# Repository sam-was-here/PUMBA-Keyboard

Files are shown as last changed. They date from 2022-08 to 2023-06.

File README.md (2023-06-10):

# PUMBA-Keyboard

PUMBA-Keyboard is a PS2 to USB macro board adapter created using the Arduino framework.

PUMBA stands for PS2 to USB Macro Board Adapter.

## Description

PUMBA-Keyboard is an Arduino project that converts a PS2 keyboard into a USB keyboard with additional features. It includes a built-in calculator and the ability to create and playback macros. The board also has a small display for showing different information.

PUMBA-Keyboard

### Features
Here is a list of features offered by PUMBA-Keyboard:
* Six different keyboard modes, allowing each key to have a different assigned macro.
* Easy on-the-fly macro creation without the need for PC software.
* All settings and macros are stored on the SD card, making modification and backup effortless.
* Calculator mode that turns a part or the whole keyboard into a calculator, sending results as keypresses.
* Numpad can be converted into a calculator in any of the six keyboard modes while leaving the rest of the keyboard untouched.
* Hex and decimal converter mode.
* Numlock is automatically enabled during startup and mode changes.
* Ability to rebind keys and have different key layouts for each keyboard mode (partially implemented).
* Key bindings can be changed without requiring the SD card to be inserted into a PC.

## Compatibility

PUMBA has been tested with SAMD21 and SAMD51 microcontroller boards. The project may work with most microcontrollers capable of emulating a HID device. However, it is not compatible with Arduino Leonardo or Uno boards due to limited available RAM. Most PS2 keyboards have been tested successfully, but it may not work with USB keyboards using a USB to PS2 adapter. The code was written using PlatformIO with the Arduino framework.

Tested Boards:
* Adafruit Feather M4 Express
* Adafruit QT Py SAMD21
* Seeeduino Xiao

## PCB and Cases

PCB and case designs are available for this project. However, they are not mandatory, as you can integrate everything inside a keyboard or use a breadboard. The repository includes KiCad project files, PDFs of the schematic, PCBs, and a bill of materials (BOM).

## Keyboard Modes

The PUMBA keyboard offers six different keyboard modes, each with its own layouts and macros. One mode is dedicated to functioning solely as a calculator, but all keyboard modes can activate the numpad as a calculator. Another mode is a hex and decimal converter, while one keyboard mode does not support macros.

When the PUMBA keyboard is plugged into a computer, it automatically enters "Keyboard 1" mode. You can switch between modes by pressing the "function key," which is set as the default to the menu button. After pressing the function key, the display shows available actions. To switch modes, press the corresponding key for the desired mode. Pressing the function key again takes you to the second-to-last mode.

### Key Assignments
Here is a list of key assignments for mode switching:
* 1: Keyboard 1
* 2: Keyboard 2
* 3: Keyboard 3
* 4: Keyboard 4
* 5: Keyboard 5
* 6: Keyboard 6
* 7: Not assigned
* 8: Hex and decimal converter
* 9: Calculator

* 0: Keyboard mode with no macros
* Shift + 1-6: Keyboard mode with calculator functionality on the numpad
* Ctrl + 1-6: Program macros/rebind keys for a key in the mode. The display provides instructions.

## Calculator Controls

The calculator mode on the PUMBA keyboard includes the following controls:
* Num Lock / Backspace: Delete the last character.
* Scroll Lock: Type out the answer using key strokes.
* Delete: Clear the current number, last number, and operator.
* =/Enter: Calculate and display the answer.
* /-+*. : Perform corresponding operations.
* x: Multiply.
* t p: Add.
* Page Up/Down: Change the number of decimal points shown.

## Macros and Key Rebinding

When creating macros, they are stored on the micro SD card inserted into the device. If no SD card is present, all keyboard modes will act as normal keyboards. If there are no settings on the SD card or it is not inserted, the device will revert to default settings.

The following Arduino libraries are used by this program:
1. PS2KeyAdvanced (located in the "lib" folder)
2. HID-Project
3. Adafruit_GFX and Adafruit_sm1306 (for OLED display support)
4. SD

To learn how to use the PS2KeyAdvanced library, refer to the documentation at [https://github.com/techpaul/PS2KeyAdvanced](https://github.com/techpaul/PS2KeyAdvanced).

This project utilizes Project-hid for USB keyboard functionality. Refer to the documentation at [https://github.com/NicoHood/HID](https://github.com/NicoHood/HID).

The PS2KeyAdvanced library in the "lib" folder has been modified to disable keypad switching keybindings and modify lock keys to prevent issues.

* Num Lock is now PS2_KEY_LANG1.
* Scroll Lock is now PS2_KEY_LANG2.
* Caps Lock is now PS2_KEY_LANG3.
* Sending data (Lock LED) to the PS2 keyboard does not work with SAMD boards.

## Changing Settings

On the PUMBA Keyboard, you can change settings such as the screen timeout duration, screen rotation, and the function key. Currently, there is no way to change these settings using the keyboard directly, but you can modify them in the code or by creating a settings file on the SD card. On startup, PUMBA looks for a config file named "CONFIG.TXT" located in the "/SETTING" folder on the SD card to apply the settings.

To change settings using the SD card, follow these steps:
1. Create a file named "CONFIG.TXT" in a folder named "SETTING" on the SD card.
2. In the config file, enter the name of the setting followed by an "=" sign. Each setting should be on a new line.
   * sleep=SETTING
     * SETTING: The duration in minutes before the screen turns off.
   * fnkey=SETTING
     * SETTING: The PS2lib key binding in decimal for the function key.
   * rotation=SETTING
     * SETTING: The screen rotation value. 0 is default, 2 is rotated 180 degrees.
3. Save the changes to the file.
4. Insert the SD card into PUMBA and plug it in.

## Key Rebinding

PUMBA now supports the ability to rebind keys for each keyboard mode. To rebind keys, create a file named "LAYOUT.TXT" and place it in the mode for which you want to rebind the keys. Each line in the file corresponds to a PS2lib key name and the corresponding HID scancode in

 decimal. In the code files, you can find a file called "default layout.txt" which contains the default key bindings. You can make a copy of this file, rename it, and modify it according to your needs. Additionally, there is a file named "layout cheatsheet.txt" that provides a helpful reference.

In any of the 6 modes, you can set macros or rebind almost any key on the keyboard. However, please note that some keys such as Scroll Lock, Num Lock, and Pause Break may not be compatible with macros or key rebindings.

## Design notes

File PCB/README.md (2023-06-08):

Located here is the KiCad project for the PCB used in the PUMBA-Keyboard. Additionally, the Gerber files are also available here.

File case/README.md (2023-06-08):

Located here is the FreeCAD model and STLs for the case of the PUMBA-Keyboard. There are two parts to the case: the main case and the face. You can 3D print them for yourself. If I recall correctly, there is a mistake in the case model that interferes with the components and the PCB. To work around this problem, you can use a Dremel tool to fix the 3D model or modify it in FreeCAD.

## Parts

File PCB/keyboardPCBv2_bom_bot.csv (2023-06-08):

Comment | Designator | Footprint | LCSC Part #
Conn_01x05_Female | J1
SolderJumper_3_Bridged12 | JP1 JP2
PS2_Port | P1
SeeeduinoXIAO | QT_Board1
Conn_01x04_Female | Screen1

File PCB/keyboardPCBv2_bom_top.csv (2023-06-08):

Comment | Designator | Footprint | LCSC Part #
BSS138 | Q1 Q2 | SOT-23-3 | C400505
R 10k | R1 R2 R3 R4 | 0603 | C25804
cheap_microSD | U1 | TF-SMD_TF-15-15 | C111196

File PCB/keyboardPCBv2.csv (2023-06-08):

Source: | /home/sam/Documents/kicad/keyboardPCBv2/keyboardPCBv2/keyboardPCBv2.kicad_sch
Date: | Sat 23 Apr 2022 04:06:03 PM CDT
Tool: | Eeschema 6.0.2
Generator: | /app/share/kicad/plugins/bom_csv_grouped_by_value_with_fp.py
Component Count: | 14
Ref | Qnty | Value | Cmp name | Footprint | Description | Vendor
Feather_Board1, | 1 | Adafruit_Feather_M0_Express | Adafruit_Feather_M0_Express | Module:Adafruit_Feather | Microcontroller module with SAMD21 Cortex-M0 MCU and SPI Flash
J2, | 1 | Conn_01x05_Female | Conn_01x05_Female | Connector_PinSocket_2.54mm:PinSocket_1x05_P2.54mm_Vertical | Generic connector, single row, 01x05, script generated (kicad-library-utils/schlib/autogen/connector/)
JP1, JP2, | 2 | SolderJumper_3_Bridged12 | SolderJumper_3_Bridged12 | Jumper:SolderJumper-3_P1.3mm_Bridged12_RoundedPad1.0x1.5mm | 3-pole Solder Jumper, pins 1+2 closed/bridged
P1, | 1 | PS2_Port | Mini-DIN_6pins_ver4 | Custom_Footprints:Connector_Mini-DIN_Female_6Pin_2rows
Q1, Q2, | 2 | BSS138 | BSS138 | Package_TO_SOT_SMD:SOT-23 | 50V Vds, 0.22A Id, N-Channel MOSFET, SOT-23
QT_Board1, | 1 | SeeeduinoXIAO | SeeeduinoXIAO | Seeeduino XIAO KICAD:Seeeduino XIAO-MOUDLE14P-2.54-21X17.8MM
R1, R2, R3, R4, | 4 | R 10k | R | Resistor_SMD:R_0603_1608Metric_Pad0.98x0.95mm_HandSolder | Resistor
Screen1, | 1 | Conn_01x04_Female | Conn_01x04_Female | Connector_PinSocket_2.54mm:PinSocket_1x04_P2.54mm_Vertical | Generic connector, single row, 01x04, script generated (kicad-library-utils/schlib/autogen/connector/)
SPI_MICROSD1, | 1 | Micro_SD_Card | Micro_SD_Card | Connector_Card:microSD_HC_Hirose_DM3D-SF | Micro SD Card Socket

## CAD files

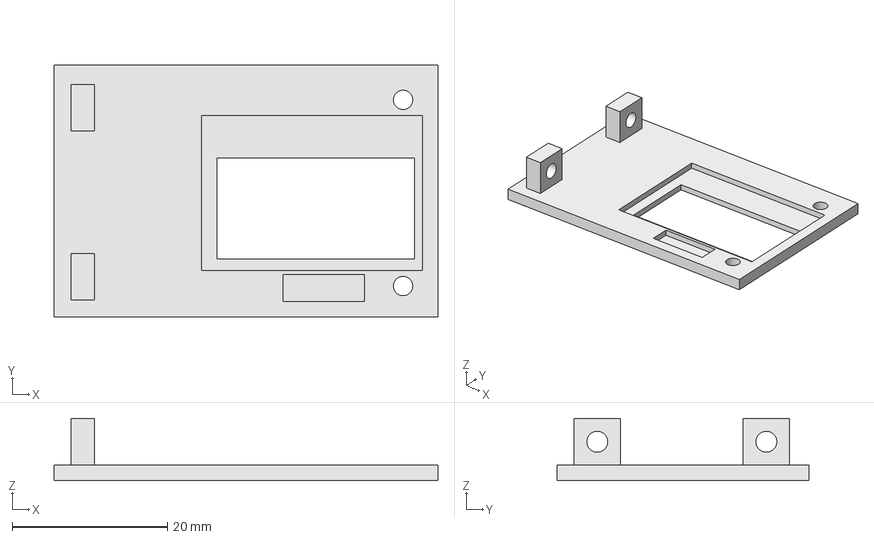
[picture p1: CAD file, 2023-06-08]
case/keyboardPCD v2 face.FCStd
49.5 x 32.5 x 8.00 mm

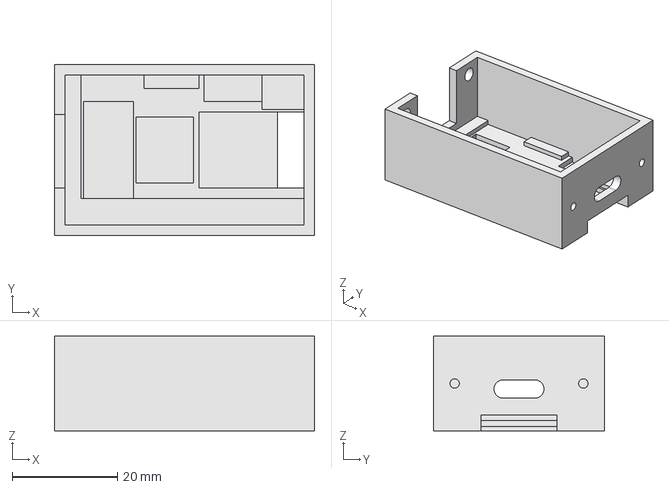
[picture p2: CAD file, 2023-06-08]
case/keyboardPCD v2 case.FCStd
49.5 x 32.5 x 18.0 mm

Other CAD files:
case/keyboardPCD v2 face-Body.stl
case/keyboardPCD v3 case-Body.stl
case/keyboardPCD v2 case-Body.stl

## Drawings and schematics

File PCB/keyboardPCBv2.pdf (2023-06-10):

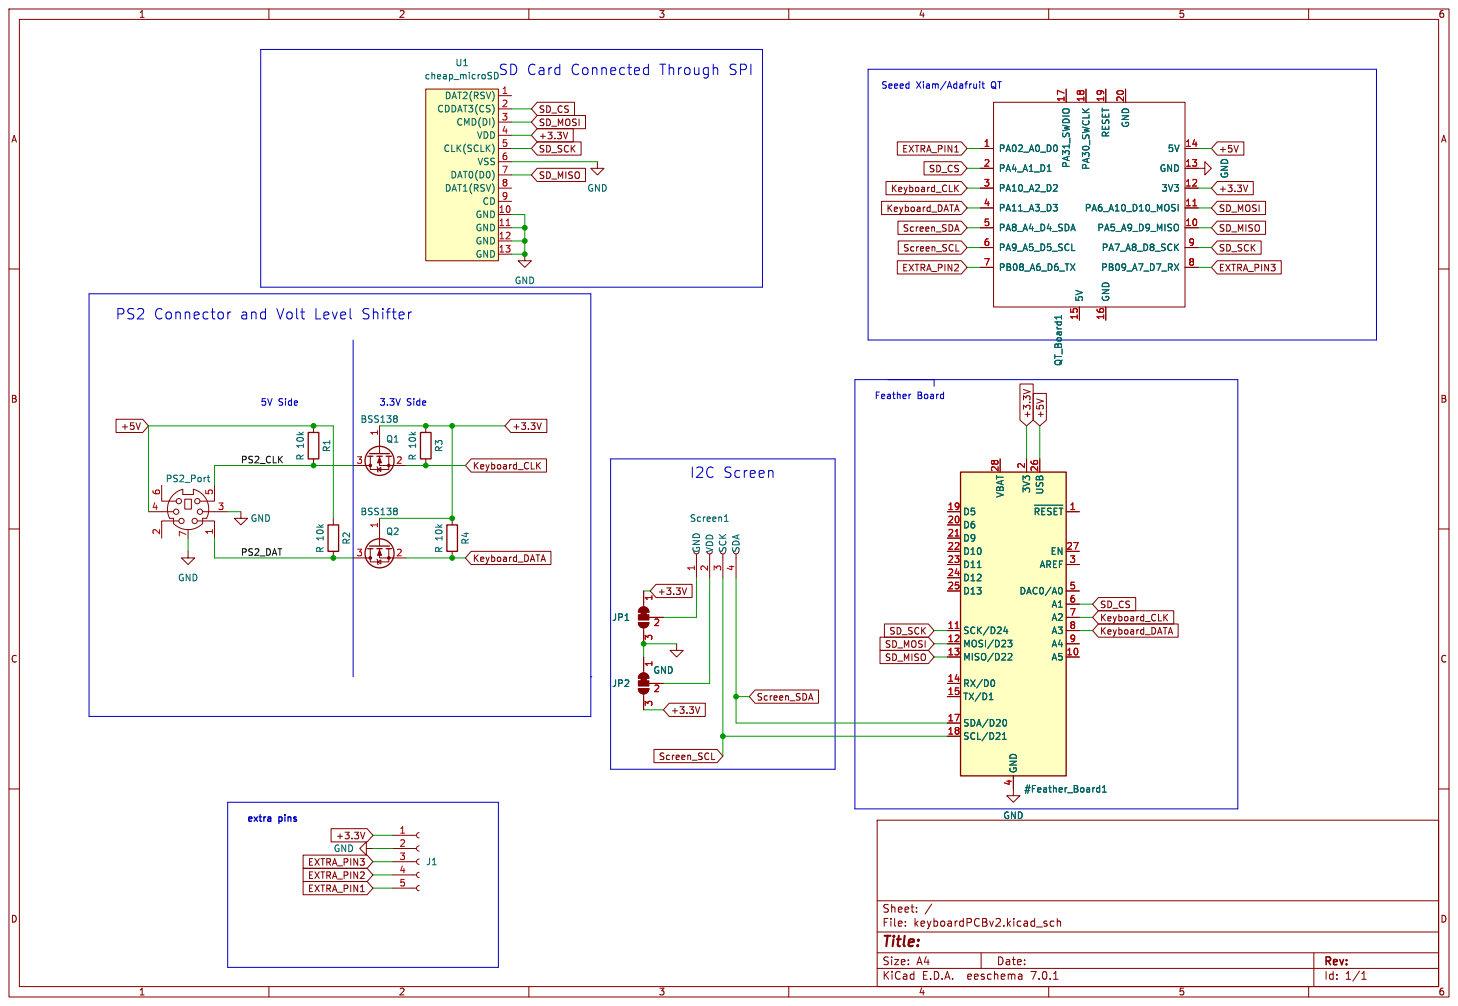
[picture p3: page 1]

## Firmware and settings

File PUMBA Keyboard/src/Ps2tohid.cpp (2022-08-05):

// <this program converts a PS2 keyboard to a USB keyboard and add extra functionality>
// Copyright (C) <2022>  <Sam Kim>

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
#include "Arduino.h"
#include "Ps2tohid.h"
#include <PS2KeyAdvanced.h>
PS2KeyAdvanced keyboard1;
#include <HID-Project.h>
#include <HID-Settings.h>
#include <SPI.h>
#include <SD.h>

#include <Wire.h>
#include <Adafruit_GFX.h>
#include <Adafruit_SSD1306.h>

// need to get from this info from begin funtion
#define SCREEN_WIDTH 128 // OLED display width, in pixels
#define SCREEN_HEIGHT 64 // OLED display height, in pixels
#define OLED_RESET -1    // Reset pin # (or -1 if sharing Arduino reset pin)
//#define SCREEN_ADDRESS 0x3C ///< See datasheet for Address; 0x3D for 128x64, 0x3C for 128x32

Adafruit_SSD1306 display1(SCREEN_WIDTH, SCREEN_HEIGHT, &Wire, OLED_RESET);

// initalized functions befor they are used
void _macroFinder();
int keyboardCheck();
bool sdStatus();
byte displayRotation();
void setLayout();

// int _solveHexDec(String currentHexDec);

/*!
    @brief  This constuter is used to set the defualt settings for the keyboard and gets things setted up. note all the setting can be change with the SD card.
    @param  interval
            The time in minuise that it takes for the display on the keyboard to turn
            off to revent screen burn in.
    @param  funcKey
            This sets what key is used as the function key. The function key is used to switch modes, hult playing macros, and stop recording macros.
    @param  flipScreen
            This rotates the screen. 0 is normal and 2 is 180 degs
    @note   Should call this befor other things in the lib and before setup. I should shang it to a function too.
*/
Ps2tohid::Ps2tohid(int interval, int funcKey = PS2_KEY_MENU, byte flipScreen = 0)
{
  _interval = _interval * interval;
  functionKey = funcKey;
  _displayRotation = flipScreen;
}

/*!
    @brief  This function initallizes everything and should only run 1 time in the setup.
    @param  dataPin1
            The pin the data line of the PS2 keyboard is connected.
    @param  clkPin2
            The pin the clock line of the PS2 keyboard is connected.
    @param  chipSelect
            The pin the SD card chipselect is connected to.
    @param  i2cAdrs
            The I2C address of the diaplay. Default is 0x3C
    @note
*/
void Ps2tohid::begin(int dataPin1, int clkPin2, int chipSelect, int i2cAdrs = 0x3C)
{
  keyboard1.begin(dataPin1, clkPin2);
  // Serial.begin(115200);
  BootKeyboard.begin();
  _sdStatus = SD.begin(chipSelect);
  display1.begin(SSD1306_SWITCHCAPVCC, i2cAdrs, false, true);

  // getting setting from sd card
  // if (_sdStatus)
  // {
  setSetting();
  setLayout();
  // }.
  BootKeyboard.releaseAll(); // release all keys when plug in keyboard, sometimes some keys are press  when they are not
}

// return true if SD card was plug in when the keyboard was powered up
bool Ps2tohid::sdStatus()
{
  return _sdStatus;
}

// returns the rotaction of the display
byte Ps2tohid::displayRotation()
{
  return _displayRotation;
}

/* This function sets all the libary settings to the settings that are stored on the SD card.
If a setting is not stored on the SD card, it will use the defualt settings.
*/
void Ps2tohid::setSetting()
{
  if (!_sdStatus) // breaks if no sd card in
    return;
  if ((SD.exists("setting/config.TXT")))
  {

    // change the setting
    String buffer;
    File dataFile = SD.open("setting/config.TXT");
    if (dataFile)
    {
      while (dataFile.available())
      {
        // Write one line to buffer
        buffer = dataFile.readStringUntil('\n');
        // test to see if line don't have #, # is a comment
        if (!buffer.startsWith("#"))
        {
          //  splits buffer it to the 2 parts. name and data parts, splits by =
          int breakIdx = buffer.indexOf('=');                  // the point the data is splited
          String settingName = buffer.substring(0, breakIdx);  // the name of the setting
          String settingData = buffer.substring(breakIdx + 1); // value of the setting

          if (settingName.equalsIgnoreCase("sleep")) // sleep timer
          {
            _interval = settingData.toInt();
            _interval = _interval * interval;
          }
          else if (settingName.equalsIgnoreCase("fnkey")) // function key
          {
            functionKey = settingData.toInt();
          }
          else if (settingName.equalsIgnoreCase("rotation")) // display flip
          {
            _displayRotation = settingData.toInt();
            display1.setRotation(_displayRotation);
          }
          else if (settingName.equalsIgnoreCase("setting4="))
          {
          }
          else if (settingName.equalsIgnoreCase("setting5="))
          {
          }
          else if (settingName.equalsIgnoreCase("setting6="))
          {
          }
          else if (settingName.equalsIgnoreCase("setting7="))
          {
          }
          else if (settingName.equalsIgnoreCase("setting8="))
          {
          }
          else if (settingName.equalsIgnoreCase("setting9="))
          {
          }
        }
      }
      dataFile.close();
    }
  }
  // update macro list
  // set all list to false
  for (int i = 0; i <= 254; i++)
  {
    _marcoKeyList1[i] = false;
    _marcoKeyList2[i] = false;
    _marcoKeyList3[i] = false;
    _marcoKeyList4[i] = false;
    _marcoKeyList5[i] = false;
    _marcoKeyList6[i] = false;
  }

  // set keys with macros to true for each mode
  for (int i = 1; i <= 6; i++)
  {
    File dir = SD.open("/" + String(i) + "/");

    while (true)
    {

      File entry = dir.openNextFile();

      if (!entry)
      {
        // no more files
        break;
      }

      String fileName = entry.name(); // turn the name of the file into a string
      if (fileName.endsWith(".TXT"))  // check to see if file or folder
      {
        switch (i) // put the macro to the mode it is for
        {
        case 1:
          _marcoKeyList1[fileName.toInt()] = true;
          break;
        case 2:
          _marcoKeyList2[fileName.toInt()] = true;
          break;
        case 3:
          _marcoKeyList3[fileName.toInt()] = true;
          break;
        case 4:
          _marcoKeyList4[fileName.toInt()] = true;
          break;
        case 5:
          _marcoKeyList5[fileName.toInt()] = true;
          break;
        case 6:
          _marcoKeyList6[fileName.toInt()] = true;
          break;
        }
      }
      entry.close();
    }
  }
  delay(100);
}
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

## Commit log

2022-06-28 can assign differnt screen i2c address
2022-06-28 can assign different screen i2c address
2022-08-05 change the typo in the folder name
    [CONFIG.TXT]
2022-08-05 fix the typo
    [CONFIG.TXT]

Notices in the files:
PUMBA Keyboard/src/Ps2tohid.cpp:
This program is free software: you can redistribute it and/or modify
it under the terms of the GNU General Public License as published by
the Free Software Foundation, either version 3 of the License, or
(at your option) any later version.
